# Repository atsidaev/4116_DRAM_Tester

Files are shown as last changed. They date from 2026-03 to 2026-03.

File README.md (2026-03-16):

# Тестер микросхем DRAM 4116

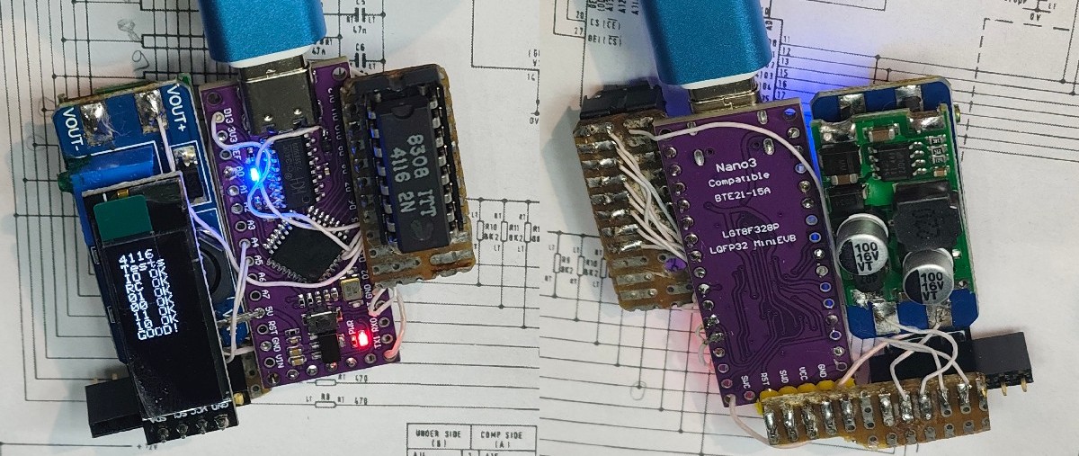
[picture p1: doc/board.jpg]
Фото платы


For English description scroll below.

Минималистичный тестер динамической памяти 4116 для быстрой проверка чипов без сложной сборки. Без реле, защитных резисторов и кнопок управления. Сборка навесным монтажом, питание +12 В и −5 В — от недорогих DC-DC модулей. Разводка позволяет подключать выводы 2–6 панельки напрямую к отверстиям платы Arduino.

Поддерживаются два варианта отображения: LCD-экран или вывод в последовательный порт. При отсутствии экрана можно ориентироваться по встроенным светодиодам: постоянное свечение — чип исправен, серия из пяти коротких вспышек — ошибка.

Проект изначально основан на [4116TesterMod](https://github.com/Wierzbowsky/4116TesterMod) от Wierzbowsky; но код в процессе разработки весь был переписан. Также упомяну [dramtester](https://github.com/zeus074/dramtester), хотя наткнулся на него уже после того, как закончил свой — в нём используются те же экран и один из DC-DC модулей. Оба они ведут свою родословную от [этого проекта](https://forum.defence-force.org/viewtopic.php?p=15035).

## Схема

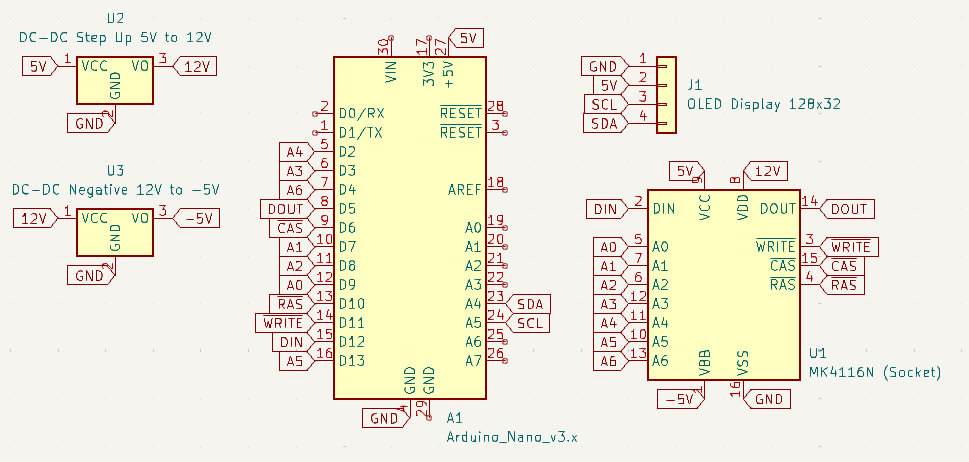
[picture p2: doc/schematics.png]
Схема


## Комплектующие

| Имя | Название | Примерная цена | Рандомная ссылка на Aliexpress |
|-----|---|---|---|
| A1 | LGT8F328P TYPE-C Arduino Nano3 Clone | $1.5 |  https://aliexpress.ru/item/1005009016874090.html |
| U1 | DIP-16 socket | $0.1 | |
| U2 | MT3608 DC-DC Adjustable Boost Module 2A | $0.4 | https://aliexpress.ru/item/1005010413039458.html |
| U3 | DC-DC Negative Voltage Power Supply Module -5V | $1 | https://aliexpress.ru/item/32902764735.html | 
| J1 | OLED module 0.91" 128X32 | $1 | https://aliexpress.ru/item/1005004572487969.html |

Сокет U1 можно взять ZIF-16. Ардуина должна подойти любая на AtMega328. U2 стоит настраиваемый только потому, что у меня был лишь такой под рукой. 
Проще взять на фиксированное напряжение 12V, типа такого: https://aliexpress.ru/item/1005007581823204.html.

## Прошивка

Используйте Arduino или PlatformIO для сборки прошивки и загрузки её в плату Arduino. 
Основной скетч-файл это firmware/firmware.ino.

При сборке через platformio все зависимости подтянутся сами, при сборке через Arduino IDE нужно 
добавить библиотеку [Adafruit SSD1306](https://docs.arduino.cc/libraries/adafruit-ssd1306/).
У неё есть две свои зависимости - Adafruit_GFX_Library и Adafruit_BusIO.

Важно! Если тоже будете использовать плату на LGT8F328, то потребуется установить пакет "lgt8fx boards" и выбрать в меню Clock Source "External 16 MHz".

## Использование

Отключите тестер от USB. Вставьте микросхему в панельку. Подключите USB. После старта контроллера запустится тестирование.

## Тесты

Во время работы выводятся двухсимвольное обозначение теста и результат: **OK** при успехе, **X** при ошибке.

| Код | Описание |
|-----|---|
| IO  | Проверка линий DI/DO на замыкание между собой |
| RC  | Проверка линий адреса на замыкание между собой |
| 10, 00, 01, 11 | Запись/чтение. Цифры — паттерн для чётных (первая) и нечётных (вторая) адресов |

---

# 4116 DRAM Tester

Minimalist tester for 4116 dynamic RAM. No relays, protection resistors, or control buttons. Built with point-to-point wiring; +12 V and −5 V are supplied by inexpensive DC-DC modules. Pinout allows connecting socket pins 2–6 directly to Arduino board holes.

Two output modes: LCD display or serial console. Without a display, status can be read from the board LEDs: steady on — chip OK, five short blinks — fault.

Originally based on [4116TesterMod](https://github.com/Wierzbowsky/4116TesterMod) by Wierzbowsky; the code was fully rewritten during development. See also [dramtester](https://github.com/zeus074/dramtester), which uses the same display and one of the DC-DC modules. Both these testers are evolutoin of this [project](https://forum.defence-force.org/viewtopic.php?p=15035).

Aimed at quick chip verification without elaborate assembly or enclosure.

## Schematic

See above

## Bill of materials

| Ref | Name | Approx. price | Random Aliexpress link |
|-----|---|---|---|
| A1 | LGT8F328P TYPE-C Arduino Nano3 Clone | $1.5 |  https://aliexpress.ru/item/1005009016874090.html |
| U1 | DIP-16 socket | $0.1 | |
| U2 | MT3608 DC-DC Adjustable Boost Module 2A | $0.4 | https://aliexpress.ru/item/1005010413039458.html |
| U3 | DC-DC Negative Voltage Power Supply Module -5V | $1 | https://aliexpress.ru/item/32902764735.html | 
| J1 | OLED module 0.91" 128X32 | $1 | https://aliexpress.ru/item/1005004572487969.html |

Socket U1 can be a ZIF-16 type. Any Arduino based on ATmega328 should work. U2 is adjustable only because that is what I had on hand.
It is simpler to use a fixed 12 V module like this one: https://aliexpress.ru/item/1005007581823204.html.

## Flashing

Use Arduino or PlatformIO to build and flash firmware. Main sketch file is firmware/firmware.ino.

When building with PlatformIO all dependencies will be pulled in automatically. When using Arduino IDE you need to install the [Adafruit SSD1306](https://docs.arduino.cc/libraries/adafruit-ssd1306/) library.
It has two dependencies of its own: Adafruit_GFX_Library and Adafruit_BusIO.

If you are using an LGT8F328-based board, install the "lgt8fx boards" package and set "Clock Source" to "External 16 MHz" in the board menu.

## Usage

Disconnect USB. Put 4116 in the socket. Connect USB. Testing will start immediately.

## Tests

Each test is shown by a two-letter code and result: **OK** on success, **X** on failure.

| Code | Description |
|---|---|
| IO | DI/DO lines short test |
| RC | Address lines short test |
| 10, 00, 01, 11 | Write/read. Digits are the pattern for even (first) and odd (second) addresses |

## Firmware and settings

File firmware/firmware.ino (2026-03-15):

#include "StateReporter.h"
#include "RamChip.h"
#include "Tester.h"

StateReporter state;

RamChip<7,7> chip;
Tester<7,7> tester(&chip);

typedef struct
{
    uint8_t v1;
    uint8_t v2;
} test;

test tests[] = { 
  { 0, 1 },
  { 0, 0 }, 
  { 1, 1 }, 
  { 1, 0 },
};

void setup() {
    state.init();
    state.println(F("4116\nTests"));

    chip.init();
}

void loop() {
    bool result = true;
    uint8_t i;

    state.print("IO ");
    result = state.logTestResult(tester.IoShortCircuitTest());

    state.print("RC ");
    bool rasCasResult = state.logTestResult(tester.RasCasTest());
    result &= rasCasResult;

    for (i = 0; i < sizeof(tests) / sizeof(test); i++)
    {
        test t = tests[i];
        state.write('0' + t.v1);
        state.write('0' + t.v2);
        state.write(' ');
        state.refresh();

        bool test_res = state.logTestResult(tester.CellTest(t.v1, t.v2));

        // Blink at the end of the test
        state.ledBlink();

        // Blink twice if test passed
        if (test_res)
            state.ledBlink();

        result &= test_res;
    }

    state.logTestResult(result, F("GOOD!"), F("FAIL!"));

    while (1) {
        if (result)
            state.ledOn();
        else
            for (i = 0; i < 5; i++)
                state.ledBlink(); 

        delay(600);
    }
}

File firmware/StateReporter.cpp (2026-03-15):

#include "StateReporter.h"

void StateReporter::init()
{
    displayInitialized = false;
    pinMode(LED, OUTPUT);
    digitalWrite(LED, LOW);

    Serial.begin(9600);
    // Wait for display
    delay(500);

    if (!display.begin(SSD1306_SWITCHCAPVCC, SCREEN_ADDRESS)) {
        Serial.println(F("SSD1306 allocation failed"));
        // Continue as we still have serial and LED
    } else {
        displayInitialized = true;

        display.clearDisplay();
        display.setRotation(1);
        display.setTextSize(1);              // Normal 1:1 pixel scale
        display.setTextColor(SSD1306_WHITE); // Draw white text
        display.setCursor(0, 0);              // Start at top-left corner
        refresh();
    }
}

size_t StateReporter::write(uint8_t c)
{
    if (displayInitialized)
        display.write(c);
    return Serial.write(c);
}

void StateReporter::refresh()
{
    if (displayInitialized)
        display.display();
}

bool StateReporter::logTestResult(bool result, const __FlashStringHelper* msg_ok, const __FlashStringHelper* msg_fail)
{
    if (result)
        this->println(msg_ok);
    else
        this->println(msg_fail);
    
    this->refresh();

    return result;
}

bool StateReporter::logTestResult(bool result)
{
    return logTestResult(result, F("OK"), F(" X"));
}

void StateReporter::ledBlink() {
    ledOn();
    delay(100);
    ledOff();
    delay(100);
}
